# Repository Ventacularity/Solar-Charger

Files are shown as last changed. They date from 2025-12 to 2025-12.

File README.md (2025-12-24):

# Solar Charger

Solar-powered Li-ion charging and power management system implemented on a custom PCB.

## Overview
This project focuses on hardware design for managing variable solar input while safely charging a Li-ion battery and delivering regulated power rails. The system integrates dedicated charge controllers, buck/boost DC-DC converters, and an ESP32 for monitoring and control.

## Key Features
- Custom PCB design for solar-powered Li-ion charging
- Buck and boost DC-DC converters for regulated 5 V and 3.3 V outputs
- Battery voltage/current sensing and power-path management
- ESP32-based monitoring and control logic

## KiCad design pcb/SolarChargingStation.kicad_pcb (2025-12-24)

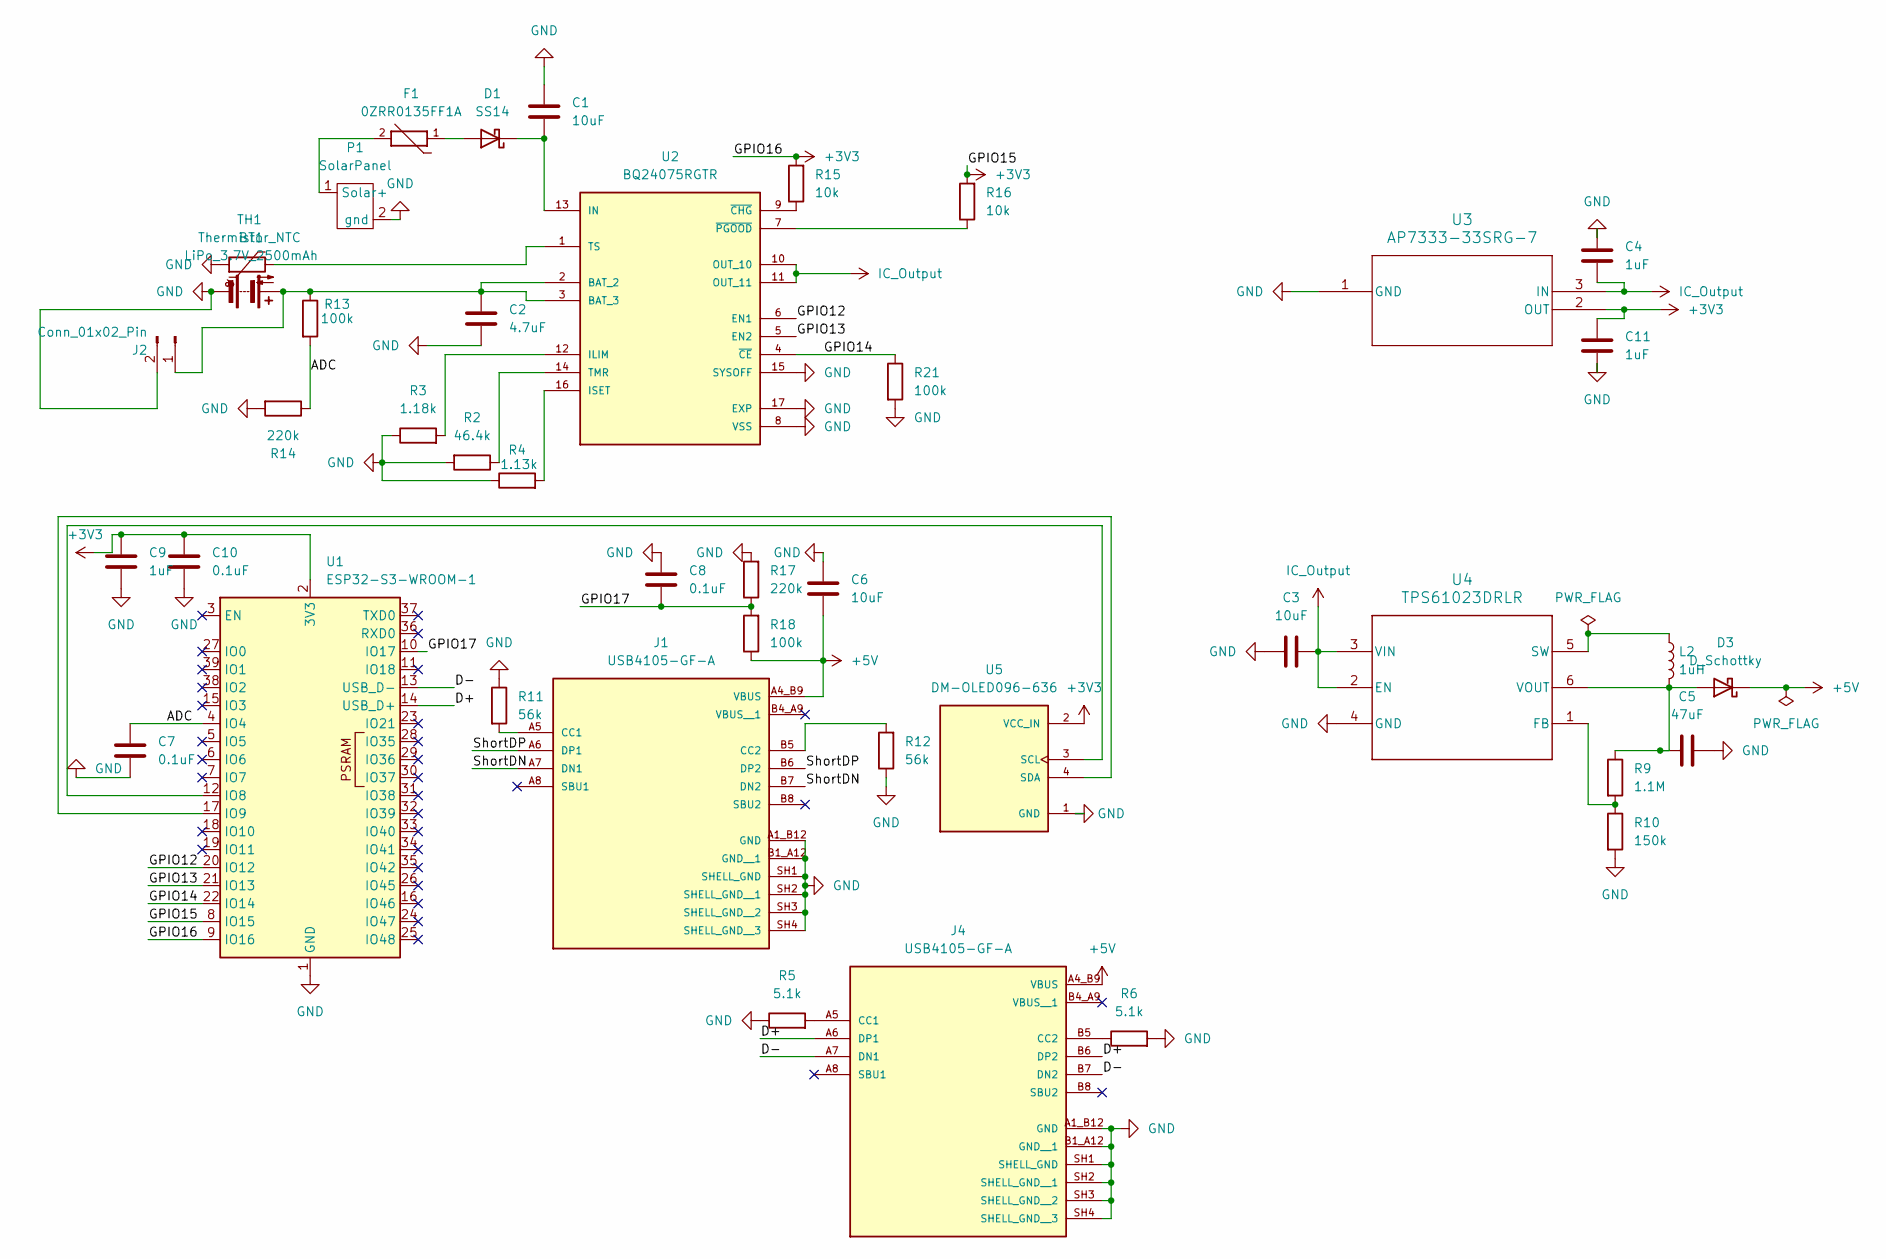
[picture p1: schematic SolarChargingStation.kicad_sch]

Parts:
BT1: LiPo_3.7V_2500mAh; JST_PH_B2B-PH-K_1x02_P2.00mm_Vertical
C1, C3, C6: 10uF; C_0805_2012Metric
C2: 4.7uF; C_0805_2012Metric
C4, C9, C11: 1uF; C_0805_2012Metric
C5: 47uF; C_0805_2012Metric
C7, C8, C10: 0.1uF; C_0805_2012Metric
D1: SS14; D_0805_2012Metric
D3: D_Schottky; D_0805_2012Metric
F1: 0ZRR0135FF1A; TRES_CMF0805_CTM; PARTREV Apr2023
J1, J4: USB4105-GF-A; GCT_USB4105-GF-A; PARTREV B4
J2: Conn_01x02_Pin; JST_PH_B2B-PH-K_1x02_P2.00mm_Vertical
L2: 1uH; L_0805_2012Metric
P1: SolarPanel; NewNewPanel
R2: 46.4k; R_0805_2012Metric
R3: 1.18k; R_0805_2012Metric
R4: 1.13k; R_0805_2012Metric
R5, R6: 5.1k; R_0805_2012Metric
R9: 1.1M; R_0805_2012Metric
R10: 150k; R_0805_2012Metric
R11, R12: 56k; R_0805_2012Metric
R13, R18, R21: 100k; R_0805_2012Metric
R14, R17: 220k; R_0805_2012Metric
R15, R16: 10k; R_0805_2012Metric
TH1: Thermistor_NTC; TRES_CMF0805_CTM
U1: ESP32-S3-WROOM-1
U2: BQ24075RGTR; QFN50P300X300X100-17N; PARTREV M
U3: AP7333-33SRG-7; SOT23R_DIO
U4: TPS61023DRLR; DRL0006A
U5: DM-OLED096-636; MODULE_DM-OLED096-636; PARTREV 2018-09-10

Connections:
+3V3: C9.1, C10.1, C11.1, R15.2, R16.2, U1.2 (3V3), U1.8 (IO15), U1.9 (IO16), U3.2 (OUT), U5.2 (VCC_IN)
+5V: C6.1, D3.1 (K), J1.A4_B9 (VBUS), J4.A4_B9 (VBUS), R18.1
/ADC: C7.1, R13.2, R14.1, U1.4 (IO4)
/D+: J4.A6 (DP1), J4.B6 (DP2), U1.14 (USB_D+)
/D-: J4.A7 (DN1), J4.B7 (DN2), U1.13 (USB_D-)
/GPIO12: U1.20 (IO12), U2.6 (EN1)
/GPIO13: U1.21 (IO13), U2.5 (EN2)
/GPIO14: R21.1, U1.22 (IO14), U2.4 (~CE)
/GPIO17: C8.1, R17.1, R18.2, U1.10 (IO17)
/ShortDN: J1.A7 (DN1), J1.B7 (DN2)
/ShortDP: J1.A6 (DP1), J1.B6 (DP2)
GND: BT1.2 (-), C1.1, C2.2, C3.1, C4.1, C5.1, C6.2, C7.2, C8.2, C9.2, C10.2, C11.2, J1.A1_B12 (GND), J1.B1_A12 (GND__1), J1.SH1 (SHELL_GND), J1.SH2 (SHELL_GND__1), J1.SH3 (SHELL_GND__2), J1.SH4 (SHELL_GND__3), J2.2, J4.A1_B12 (GND), J4.B1_A12 (GND__1), J4.SH1 (SHELL_GND), J4.SH2 (SHELL_GND__1), J4.SH3 (SHELL_GND__2), J4.SH4 (SHELL_GND__3), P1.2 (gnd), R2.2, R3.1, R4.1, R5.1, R6.2, R10.2, R11.1, R12.1, R14.2, R17.2, R21.2, TH1.1, U1.1 (GND), U1.40 (GND), U1.41 (GND), U2.8 (VSS), U2.15 (SYSOFF), U2.17 (EXP), U2.18, U2.19, U2.20, U2.21, U2.22, U3.1 (GND), U4.4 (GND), U5.1 (GND)
IC_Output: C3.2, C4.2, U2.10 (OUT_10), U2.11 (OUT_11), U3.3 (IN), U4.2 (EN), U4.3 (VIN)
unnamed: BT1.1 (+), C2.1, J2.1, R13.1, U2.2 (BAT_2), U2.3 (BAT_3)
unnamed: D1.2 (A), F1.1
unnamed: C1.2, D1.1 (K), U2.13 (IN)
unnamed: C5.2, D3.2 (A), L2.2, R9.1, U4.6 (VOUT)
unnamed: J1.A5 (CC1), R11.2
unnamed: J1.B5 (CC2), R12.2
unnamed: J4.A5 (CC1), R5.2
unnamed: J4.B5 (CC2), R6.1
unnamed: F1.2, P1.1 (Solar+)
unnamed: U1.12 (IO8), U5.3 (SCL)
unnamed: U1.17 (IO9), U5.4 (SDA)
unnamed: R3.2, U2.12 (ILIM)
unnamed: R4.2, U2.16 (ISET)
unnamed: R2.1, U2.14 (TMR)
unnamed: TH1.2, U2.1 (TS)
unnamed: R15.1, U2.9 (~CHG)
unnamed: R16.1, U2.7 (~PGOOD)
unnamed: R9.2, R10.1, U4.1 (FB)
unnamed: L2.1, U4.5 (SW)

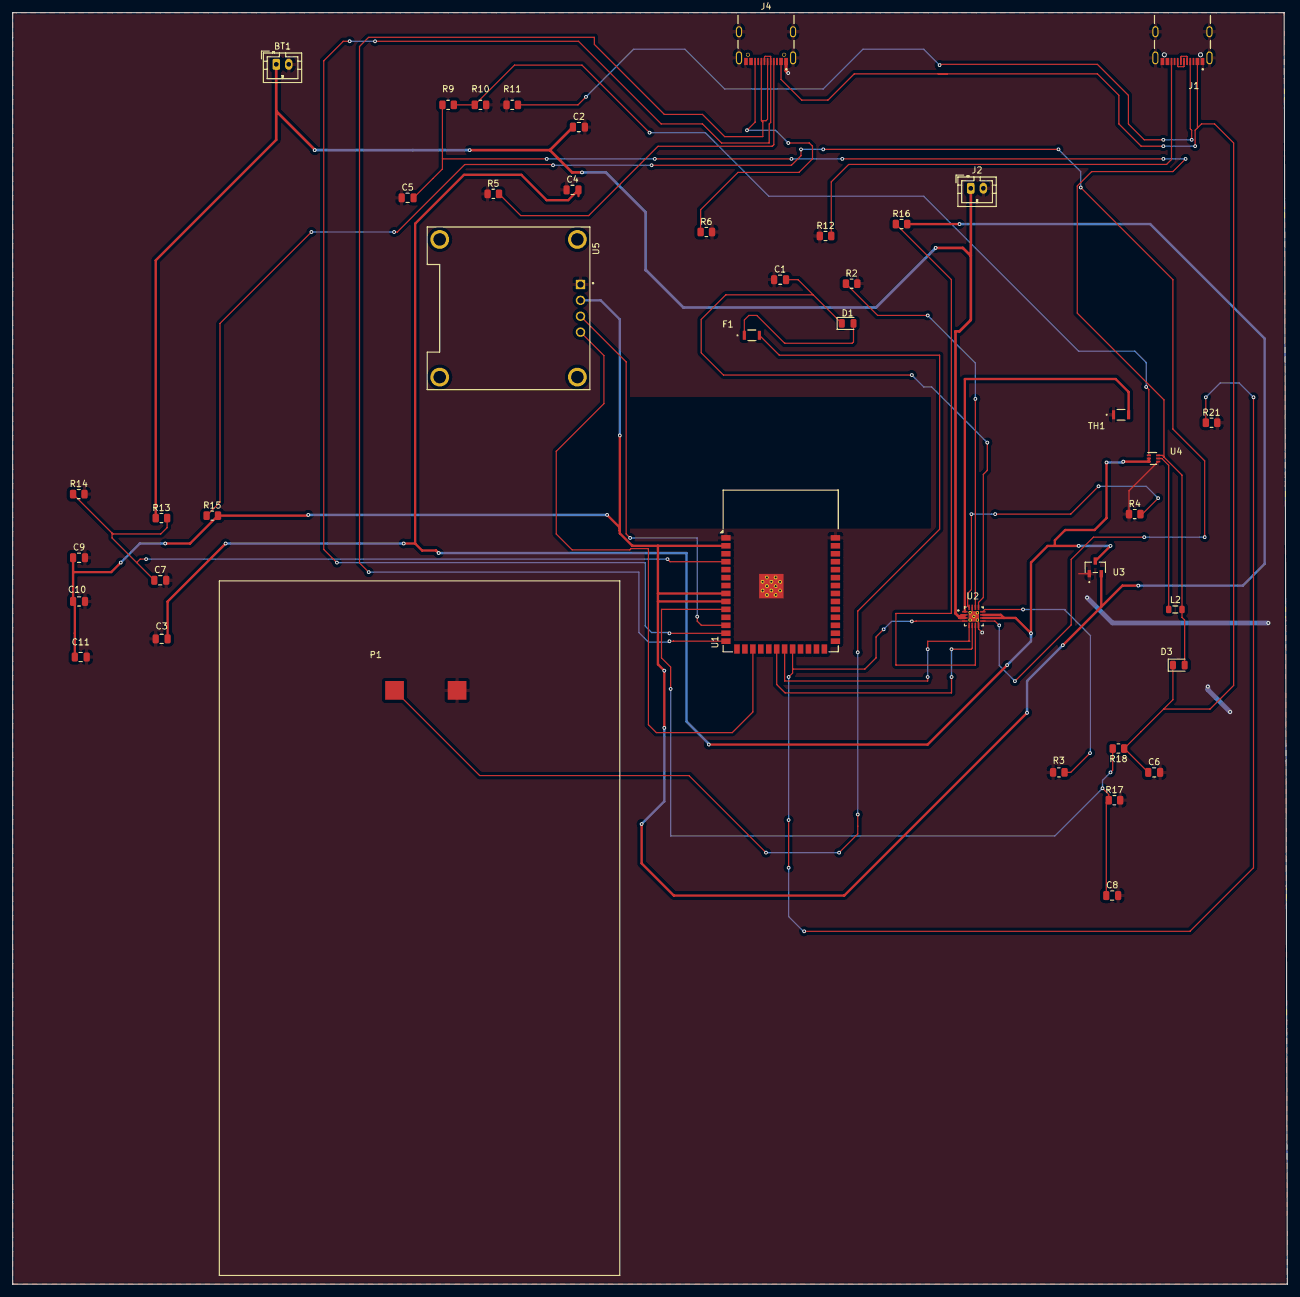
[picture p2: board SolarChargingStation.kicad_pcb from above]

Board: 2 copper layers, 203.7 x 203.2 mm, 42 parts (0 on the bottom side), 32 nets.

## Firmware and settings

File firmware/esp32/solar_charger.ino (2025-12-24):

#include <Wire.h>
#include <Adafruit_GFX.h>
#include <Adafruit_SSD1306.h>

#define SCREEN_WIDTH 128
#define SCREEN_HEIGHT 64
Adafruit_SSD1306 display(SCREEN_WIDTH, SCREEN_HEIGHT, &Wire, -1);

// ----------------------------------------------------------
// PIN ASSIGNMENTS 
// ----------------------------------------------------------
#define PIN_PGOOD     15   // BQ24075 PGOOD (input detected)
#define PIN_CHG       16   // BQ24075 CHG (active LOW when charging)
#define PIN_CE        14   // BQ24075 CE (LOW = charging enabled)
#define PIN_EN1       12   // BQ24075 EN1
#define PIN_EN2       13   // BQ24075 EN2

// ADC pins
#define PIN_ADC_BAT    4   // Battery voltage sense via R13=100k / R14=220k
#define PIN_ADC_VBUS  17   // 5V output sense via R18=100k / R17=220k

// OLED I2C pins
#define PIN_I2C_SDA   21
#define PIN_I2C_SCL   22

// ----------------------------------------------------------
// DIVIDERS 
// ----------------------------------------------------------

// Battery divider R13 = 100k (top), R14 = 220k (bottom)
const float R_BAT_TOP    = 100000.0f;
const float R_BAT_BOTTOM = 220000.0f;

// 5V sense divider R18 = 100k (top), R17 = 220k (bottom)
const float R_VBUS_TOP    = 100000.0f;
const float R_VBUS_BOTTOM = 220000.0f;

// ADC configuration
const float ADC_REF = 3.3f;
const int   ADC_RES = 4095;

// Li-ion battery voltage range
const float V_BAT_MIN = 3.0f;
const float V_BAT_MAX = 4.2f;

// 5V rail detection thresholds
const float VBUS_PRESENT_MIN = 4.2f;  // 5V rail alive
const float VBUS_GOOD_THRESH = 4.8f;  // no significant load


// ----------------------------------------------------------
// HELPER FUNCTIONS
// ----------------------------------------------------------
float readDividerVoltage(int pin, float Rtop, float Rbottom) {
    int raw = analogRead(pin);
    float v_adc = (raw * ADC_REF) / ADC_RES;
    float ratio = (Rtop + Rbottom) / Rbottom;
    return v_adc * ratio;
}

int batteryPercent(float vbat) {
    if (vbat <= V_BAT_MIN) return 0;
    if (vbat >= V_BAT_MAX) return 100;
    return (int)(((vbat - V_BAT_MIN) / (V_BAT_MAX - V_BAT_MIN)) * 100.0f);
}


// ----------------------------------------------------------
// SETUP
// ----------------------------------------------------------
void setup() {
    Serial.begin(115200);

    pinMode(PIN_PGOOD, INPUT);
    pinMode(PIN_CHG,   INPUT);

    pinMode(PIN_CE,  OUTPUT);
    pinMode(PIN_EN1, OUTPUT);
    pinMode(PIN_EN2, OUTPUT);

    // Default charger behavior: charging enabled, USB-charge mode
    digitalWrite(PIN_CE,  LOW);
    digitalWrite(PIN_EN1, LOW);
    digitalWrite(PIN_EN2, LOW);

    // Configure ADC input attenuation
    analogReadResolution(12);
    analogSetPinAttenuation(PIN_ADC_BAT,  ADC_11db);
    analogSetPinAttenuation(PIN_ADC_VBUS, ADC_11db);

    // Initialize OLED
    Wire.begin(PIN_I2C_SDA, PIN_I2C_SCL);
    if (!display.begin(SSD1306_SWITCHCAPVCC, 0x3C)) {
        Serial.println("SSD1306 allocation failed");
        for (;;) {}
    }

    display.clearDisplay();
    display.setTextSize(1);
    display.setTextColor(SSD1306_WHITE);
    display.setCursor(0, 0);
    display.println("HOPE Solar Charger");
    display.println("Booting...");
    display.display();
    delay(1200);
}


// ----------------------------------------------------------
// MAIN LOOP
// ----------------------------------------------------------
void loop() {

    // -------- Read voltages ----------
    float vbat = readDividerVoltage(PIN_ADC_BAT, R_BAT_TOP, R_BAT_BOTTOM);
    float vbus = readDividerVoltage(PIN_ADC_VBUS, R_VBUS_TOP, R_VBUS_BOTTOM);

    int pct = batteryPercent(vbat);

    // BQ24075 digital signals
    bool solar = digitalRead(PIN_PGOOD);    // input present
    bool chg   = (digitalRead(PIN_CHG) == LOW);  // charging active
    bool full  = (pct >= 98);

    // Auto CE disable on full battery
    digitalWrite(PIN_CE, full ? HIGH : LOW);

    // 5V rail / device load inference
    bool vbusPresent = (vbus >= VBUS_PRESENT_MIN);
    bool vbusStrong  = (vbus >= VBUS_GOOD_THRESH);

    bool deviceCharging = false;
    const char *vbusStatus;

    if (!vbusPresent) {
        vbusStatus = "Off";
        deviceCharging = false;
    } else if (vbusStrong) {
        vbusStatus = "OK";
        deviceCharging = false;  // nearly no load
    } else {
        vbusStatus = "Low";      // sagging → load
        deviceCharging = true;
    }

    // --------- Serial Debug ---------
    Serial.print("Vbat=");
    Serial.print(vbat);
    Serial.print("  (");
    Serial.print(pct);
    Serial.print("%)   Vbus=");
    Serial.print(vbus);
    Serial.print("   Device=");
    Serial.println(deviceCharging ? "CHARGING" : "none");


    // ----------------------------------------------------------
    // OLED OUTPUT 
    // ----------------------------------------------------------
    display.clearDisplay();
    display.setCursor(0, 0);
    display.setTextSize(1);

    display.print("Bat: ");
    display.print(vbat, 2);
    display.print("V  ");
    display.print(pct);
    display.println("%");

    display.print("Input: ");
    display.println(solar ? "Solar/USB" : "None");

    display.print("Charge: ");
    if (full) display.println("FULL");
    else if (chg) display.println("Charging");
    else display.println("Idle");

    display.print("ChgEn: ");
    display.println(full ? "OFF" : "ON");

    display.print("5V: ");
    display.println(vbusStatus);

    display.print("Device: ");
    display.println(deviceCharging ? "Charging" : "Not Detected");

    display.display();

    delay(1000);
}

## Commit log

2025-12-24 Revise README for Solar Charger project
    Updated project description and added key features and technologies.
2025-12-24 Refactor README to remove duplicate ESP32 mention
    Removed duplicate mention of ESP32-based monitoring and control logic from the Key Features section and updated the Tools & Technologies section.
2025-12-24 add charger
    [SolarChargingStation-B_Cu.gbr, SolarChargingStation-B_Mask.gbr, SolarChargingStation-B_Paste.gbr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]
2025-12-24 add ESP32 Arduino firmware for solar charger
